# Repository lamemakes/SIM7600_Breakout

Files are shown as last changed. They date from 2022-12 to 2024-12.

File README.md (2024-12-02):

# SIM7600 Breakout Board
*Needs a cooler name, huh?*

## TLDR
This project is a 4 layer PCB built around the SIM7600 to expose all of it's functionality to make it usable/hackable for a wide range of devices, with a form factor that can fit beautifully on a 30 row breadboard.

## Why?
The intent of this was to be able to experiment with 4G/LTE, learn more about how cellular networks function, and to eventually build something that utilizes these networks along with the SIM7600.

## KiCAD
The required symbols/footprints/3D models can be found in the directories: lib_sch/sim7600_breakout.pretty/3dmodels respectively.

## Usage Pre-Requisites
- A fully assembled lamemakes SIM7600 Breakout Board
- Antennas for respective purposes
    - 50Ω passive LTE/4G w/ U.FL connector
    - 50Ω **active/powered** GPS/GNSS w/ U.FL connector)
- An activated Nano SIM card
    - Carrier _shouldn't_ matter, see **IMEI** section
- Device that supports some form of serial communication
    - UART, I2C, and SPI are all supported.
- _(Optional)_ Wired headphones, ideally with about a 35Ω impedence.

## Usage 
The breakout board can be initialized by connecting +3.3v to the +3v3 pin, and ground to the GND pin. Then, turn the module on by pulling the PKEY HIGH.

## Pics

*Schematic*
SIM7600 Breakout Board Schematic

*PCB*
SIM7600 Breakout Board Schematic

## Notes
- **Be a good neighbor on the RF spectrum!** There is certainly a lot of grey area when it comes to legality and LTE/carrier service, so be conscientious - stay within local law. 
- As of writing (12/09/22) this has yet to be constructed. The OSH Park order is out, but the SIM7600G-H is backordered at Digikey along with literally every other SIM7600 model. Hoping for a restock before the new year.
- Contribute! This is my first real RF/4G PCB, so if you see somewhere that could be improved feel free to raise an issue or put up a PR.
- As this is assembled and tinkered with, this README will be immensely updated for better usage instructions.
- It's clear the language barrier is an issue when it comes to the SIM7600 docs, but these resources helped me out a ton:
    - [Xinyuan LilyGO/T](https://github.com/Xinyuan-LilyGO/T-SIM7600X)
    - [CircuitMess Ringo](https://github.com/CircuitMess/CircuitMess-Ringo) <- such a cool project, look to do something very similar moving forward
    - [Waveshare SIM7600 HAT docs](https://www.waveshare.com/wiki/SIM7600E-H_4G_HAT)

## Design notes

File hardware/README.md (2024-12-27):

# SIM7600 Breakout Board Hardware

## BOM

A list of the parts used & where they can be found

| Part No. | Ref Des | Link | Quantity | Notes |
| --- | --- | --- | --- | --- |
| 2137160001 | `J5` | [Digikey](https://www.digikey.com/en/products/detail/molex/2137160001/13662558) | | USB C 2.0 Receptacle |
| SIM7600G R2 | `U3` | [Digikey](https://www.digikey.com/en/products/detail/simcom-wireless-solutions-limited/SIM7600G-R2/15841466) | 1 | SIMCom Wireless LTE Module |
| NAU8810YG | `U4` | [Digikey](https://www.digikey.com/en/products/detail/nuvoton-technology-corporation/NAU8810YG/4271435) | 1 | Audio Codec |
| NVT2008PW,118 | `U1`, `U2` | [Digikey](https://www.digikey.com/en/products/detail/nxp-usa-inc/nvt2008pw-118/2530413) | 2 | Serial Logic Shifter |
| SIM8060-6-0-14-00-A | `J1` | [Digikey](https://www.digikey.com/en/products/detail/gct/sim8060-6-0-14-00-a/9859630) | 1 | Nano SIM Card Holder |
| MMBT3904L RFG | `Q1` | [Digikey](https://www.digikey.com/en/products/detail/taiwan-semiconductor-corporation/mmbt3904l-rfg/7357838) | 1 | NPN BJT for SIM7600 Power Key |
| PESD2V0Y1BSFYL | `D5` | [Digikey](https://www.digikey.com/en/products/detail/nexperia-usa-inc/pesd2v0y1bsfyl/8628181) | 1 | TVS Diode |
| ESD9L5.0ST5G | `D3`, `D4` | [Digikey](https://www.digikey.com/en/products/detail/onsemi/ESD9L5-0ST5G/1693175) | 2 | TVS Diode (USB Data) |
| U.FL-R-SMT-1(01) | `J6`, `J7`, `J8` | [Digikey](https://www.digikey.com/en/products/detail/hirose-electric-co-ltd/U-FL-R-SMT-1-01/3978494) | 3 | Male U.FL 50Ω Receptacle |
| MJ-3502N | `J3` | [Digikey](https://www.digikey.com/en/products/detail/cui-devices/MJ-3502N/281266) | 1 | 3.5mm Headphone Phone Jack |
| AOM-4542P-R | `MK1` | [Digikey](https://www.digikey.com/en/products/detail/pui-audio-inc/AOM-4542P-R/1745490) | 1 | Analog Condenser Microphone |
| C0603C220J5GACTU | `C1`, `C2`, `C3` | [Digikey](https://www.digikey.com/en/products/detail/kemet/C0603C220J5GACTU/411055) | 3 | 22pF caps |
| CL10B104KO8NNNC | `C4`, `C9`, `C10`, `C12` | [Digikey](https://www.digikey.com/en/products/detail/samsung-electro-mechanics/CL10B104KO8NNNC/3886663) | 1 | 0.1uF cap |
| CL10A106MQ8NNNC | `C5` | [Digikey](https://www.digikey.com/en/products/detail/samsung-electro-mechanics/CL10A106MQ8NNNC/3886777) | 1 | 10uF cap |
| CL10A475KP8NNNC | `C6`, `C23`, `C24`, `C25`, `C26` | [Digikey](https://www.digikey.com/en/products/detail/samsung-electro-mechanics/CL10A475KP8NNNC/3886702) | 1 | 4.7uF cap |
| CL10B105KP8NNNC | `C7`, `C8` | [Digikey](https://www.digikey.com/en/products/detail/samsung-electro-mechanics/CL10B105KP8NNNC/3887604) | 1 | 1uF cap |
| CL10C330JB8NNNC | `C27` | [Digikey](https://www.digikey.com/en/products/detail/samsung-electro-mechanics/CL10C330JB8NNNC/3886728) | 1 | 33pF cap |
| GRM188R60J476ME15D  | `C19`, `C22` | [Digikey](https://www.digikey.com/en/products/detail/murata-electronics/GRM188R60J476ME15D/5877410) | 2 | 47uF cap |
| 150120RS75000 | `D1`, `D2` | [Digikey](https://www.digikey.com/en/products/detail/w%C3%BCrth-elektronik/150120RS75000/4489939) | 2 | Red LED |
| M20-9990245 | `J2` | [Digikey](https://www.digikey.com/en/products/detail/harwin-inc/M20-9990245/3728225) | 1 | 1x2 2.54mm male header pins |
| BSCH0010050547NJCP  | `L1` | [Digikey](https://www.digikey.com/en/products/detail/pulse-electronics/BSCH0010050547NJCP/10508660) | 1 | 47nH inductor |
| RC0201JR-0747KL | `R1`, `R2`, `R3`, `R9`, `R10`, `R11`, `R12`, `R13` | [Digikey](https://www.digikey.com/en/products/detail/yageo/RC0201JR-0747KL/1948954) | 8 | 47kΩ resistor |
| RC0201FR-074K7L | `R4`, `R8`, `R19`, `R20`, `R21` | [Digikey](https://www.digikey.com/en/products/detail/yageo/RC0201FR-074K7L/1948894) | 5 | 4k7Ω resistor |
| RC0201JR-075K1L | `R5`, `R24` | [Digikey](https://www.digikey.com/en/products/detail/yageo/RC0201JR-075K1L/5280770) | 1 | 5k1Ω resistor |
| RC0201FR-0722RL | `R6`, `R7` | [Digikey](https://www.digikey.com/en/products/detail/yageo/RC0201FR-0722RL/5280378) | 2 | 22Ω resistor |
| RC0201FR-071K3L | `R14`, `R15` | [Digikey](https://www.digikey.com/en/products/detail/yageo/RC0201FR-071K3L/3202386) | 2 | 1k3Ω resistor |
| RC0201FR-07390RL | `R16`, `R17` | [Digikey](https://www.digikey.com/en/products/detail/yageo/RC0201FR-07390RL/3202404) | 2 | 390Ω resistor |
| RC0201FR-0710RL | `R18` | [Digikey](https://www.digikey.com/en/products/detail/yageo/RC0201FR-0710RL/1948874) | 1 | 10Ω resistor |
| RC0201FR-072K2L | `R22`, `R23` | [Digikey](https://www.digikey.com/en/products/detail/yageo/RC0201FR-072K2L/5280432) | 2 | 2k2Ω resistor |

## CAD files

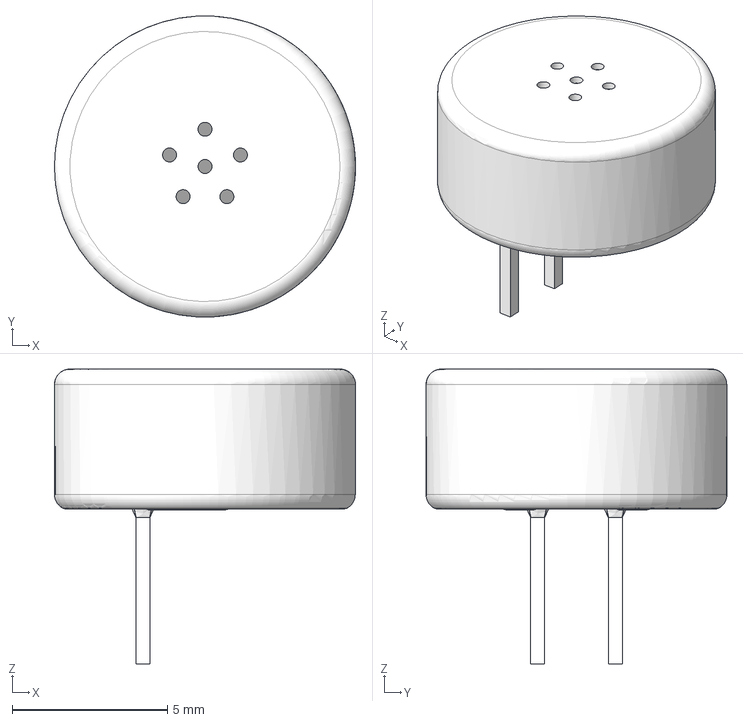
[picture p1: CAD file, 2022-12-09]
hardware/v0.1/3dmodels/AOM-4544P-NF-R.step
9.70 x 9.70 x 9.50 mm

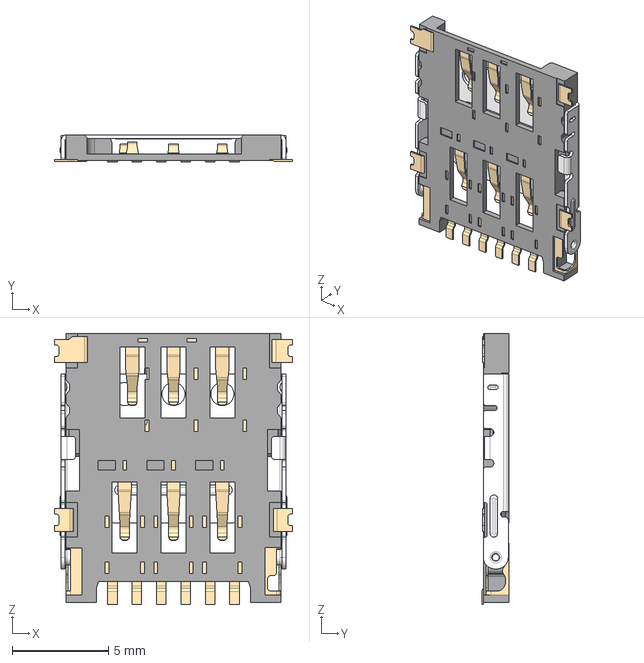
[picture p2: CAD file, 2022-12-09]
hardware/v0.1/3dmodels/SIM8060-6-0-14-00-A.stp
12.4 x 1.43 x 14.1 mm
SIM8060-6-0-14-00-A_PART2
SIM8060-6-0-14-00-A_PART1

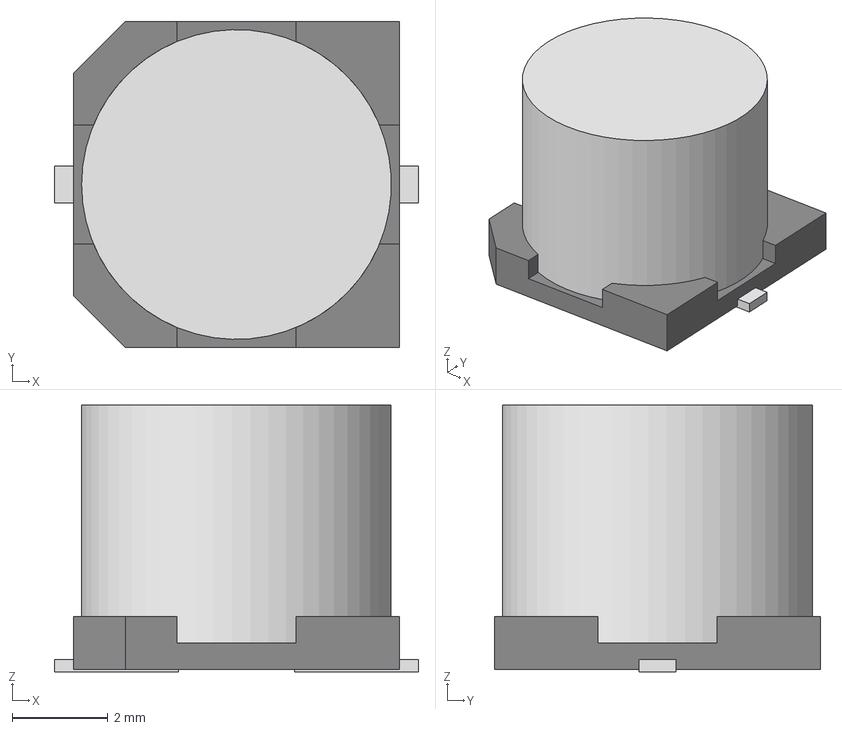
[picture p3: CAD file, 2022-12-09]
hardware/v0.1/3dmodels/CAP_0543009_WRE.step
7.59 x 6.81 x 5.57 mm

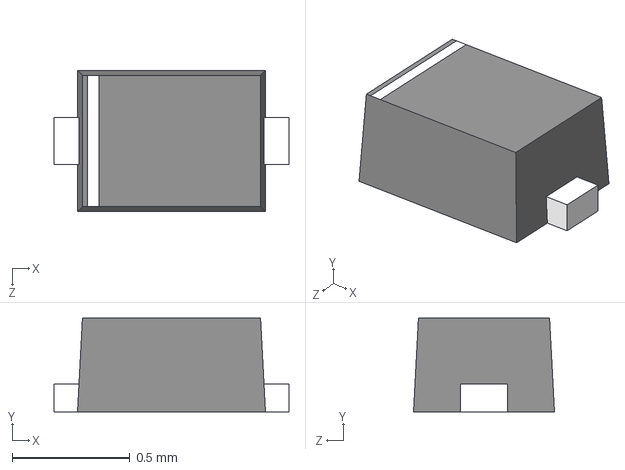
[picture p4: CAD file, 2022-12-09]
hardware/v0.1/3dmodels/ESD9L5.0ST5G.step
1 x 0.4 x 0.6 mm

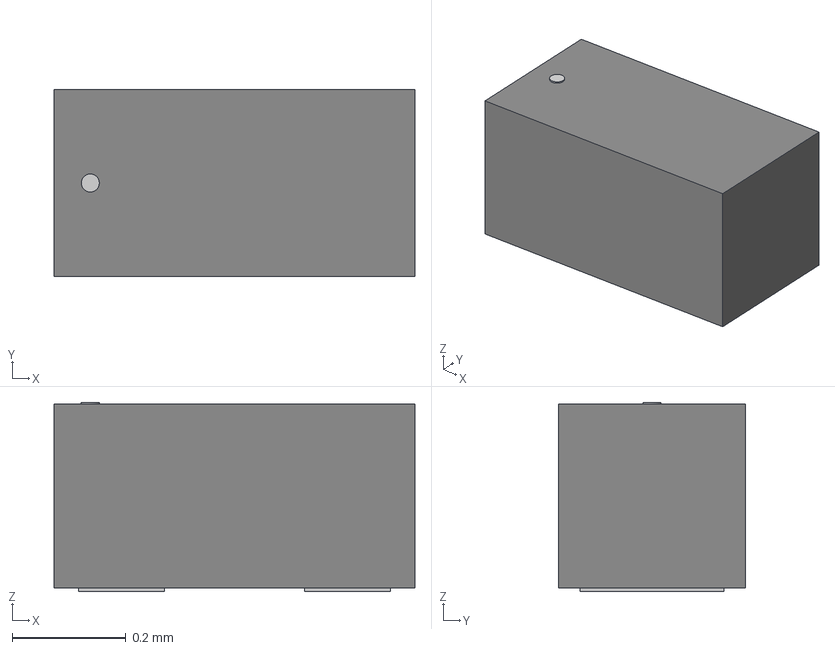
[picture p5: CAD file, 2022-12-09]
hardware/v0.1/3dmodels/CR_Y1BSFYL_NEX.step
0.636 x 0.33 x 0.333 mm

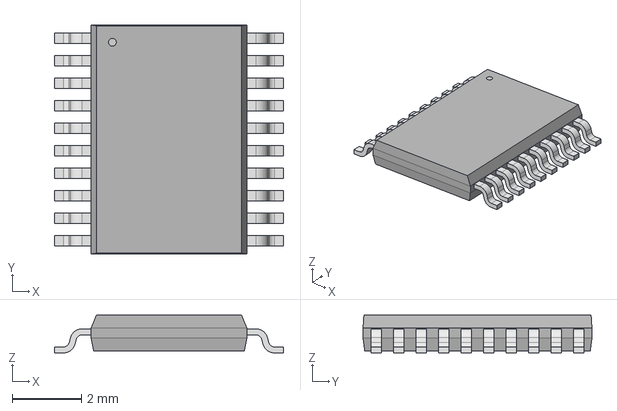
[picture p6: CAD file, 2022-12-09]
hardware/v0.1/3dmodels/TSSOP20_SOT360-1_NXP.step
6.60 x 6.60 x 1.09 mm

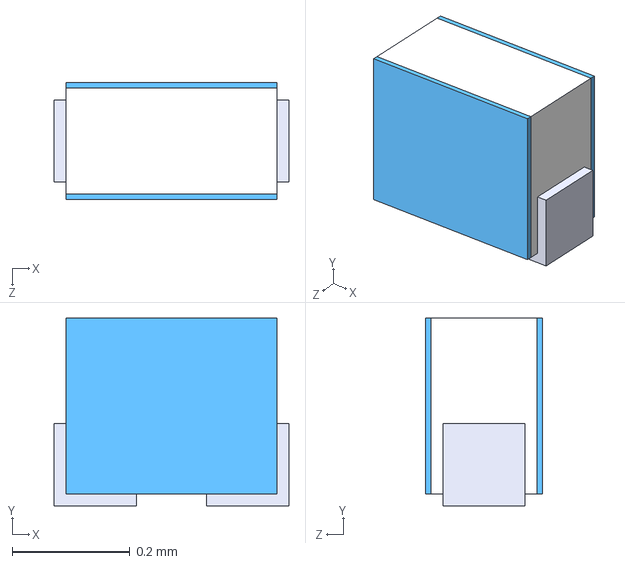
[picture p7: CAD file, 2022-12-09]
hardware/v0.1/3dmodels/LQP02HQ47NH02E.step
0.4 x 0.32 x 0.2 mm

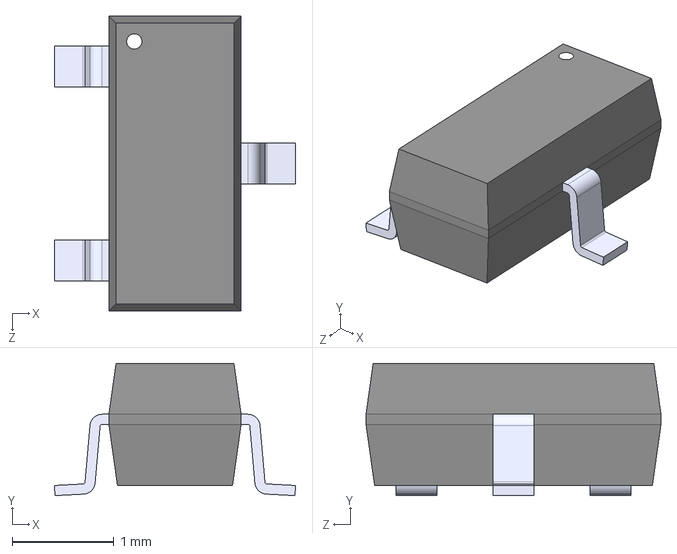
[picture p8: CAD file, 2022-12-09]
hardware/v0.1/3dmodels/MMBT3904L_RFG.step
2.37 x 1.30 x 2.90 mm

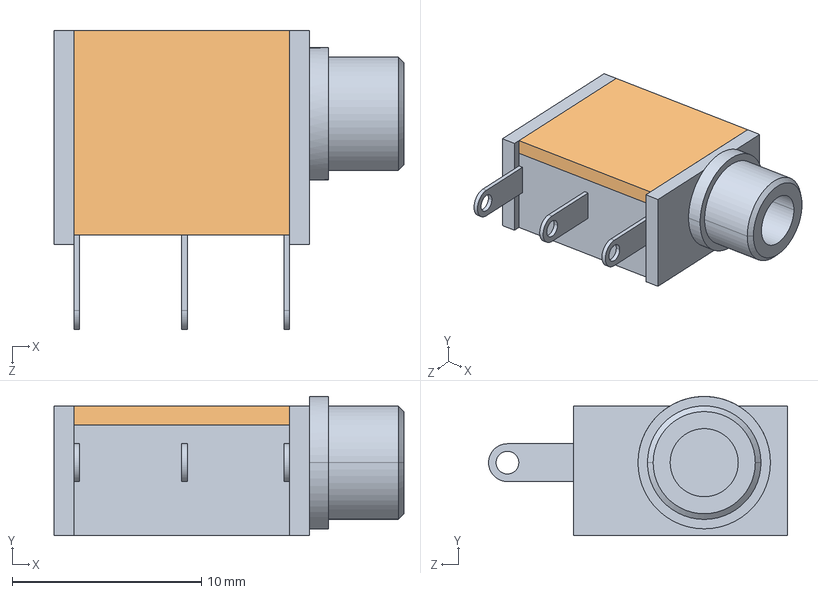
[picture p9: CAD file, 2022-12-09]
hardware/v0.1/3dmodels/CUI_DEVICES_MJ-3502N.step
18.5 x 7.35 x 15.8 mm

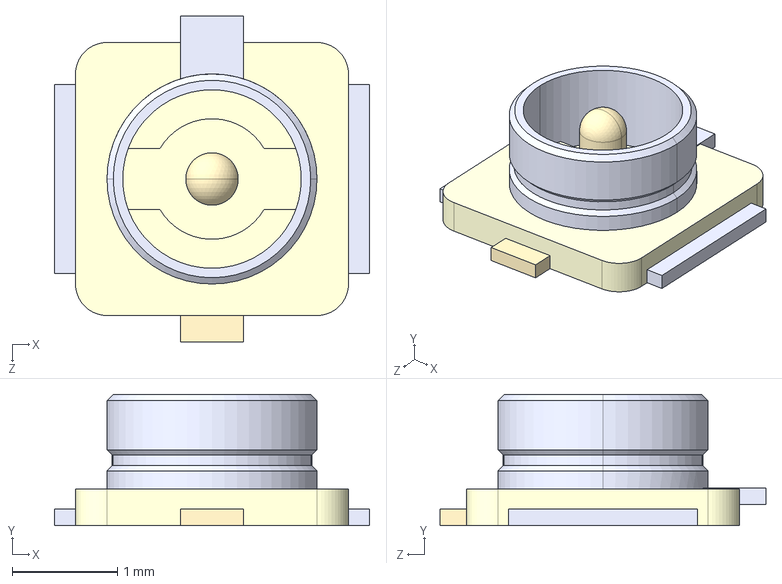
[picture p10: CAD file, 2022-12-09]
hardware/v0.1/3dmodels/U.FL-R-SMT-1_01_.step
3.00 x 1.25 x 3.10 mm

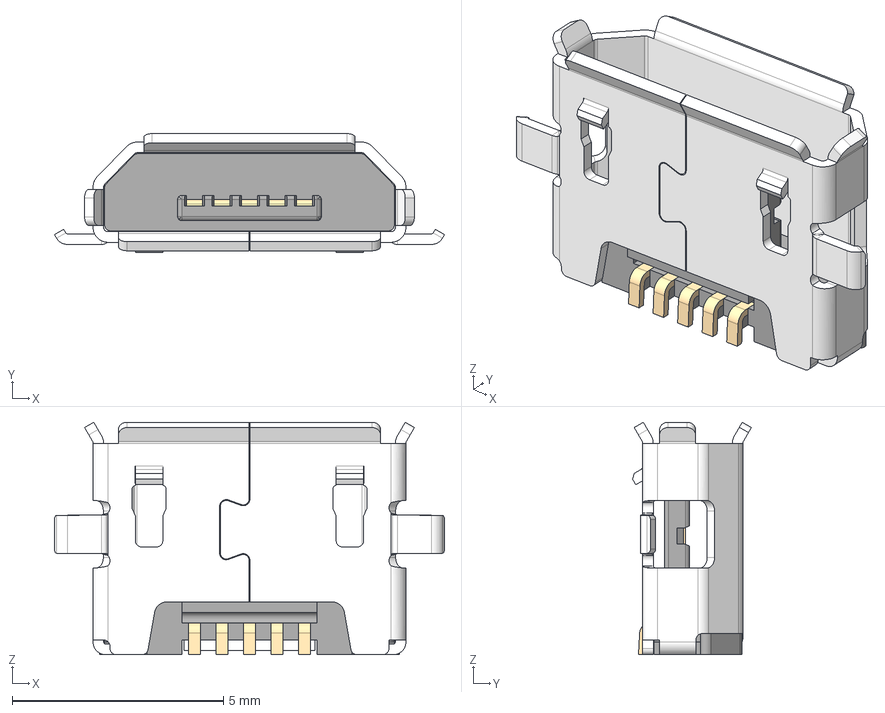
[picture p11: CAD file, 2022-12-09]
hardware/v0.1/3dmodels/usb3100_30_a.stp
9.23 x 2.81 x 5.50 mm
usb3100_30_a_PART7
usb3100_30_a_PART6
usb3100_30_a_PART5
usb3100_30_a_PART4
usb3100_30_a_PART3
usb3100_30_a_PART2
usb3100_30_a_PART1

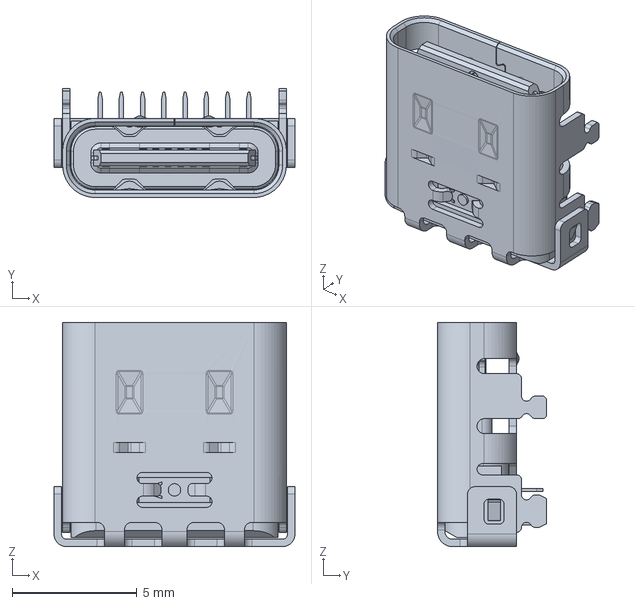
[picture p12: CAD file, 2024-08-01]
hardware/v0.1/3dmodels/2137160001-USB-C.stp
9.64 x 4.36 x 8.97 mm

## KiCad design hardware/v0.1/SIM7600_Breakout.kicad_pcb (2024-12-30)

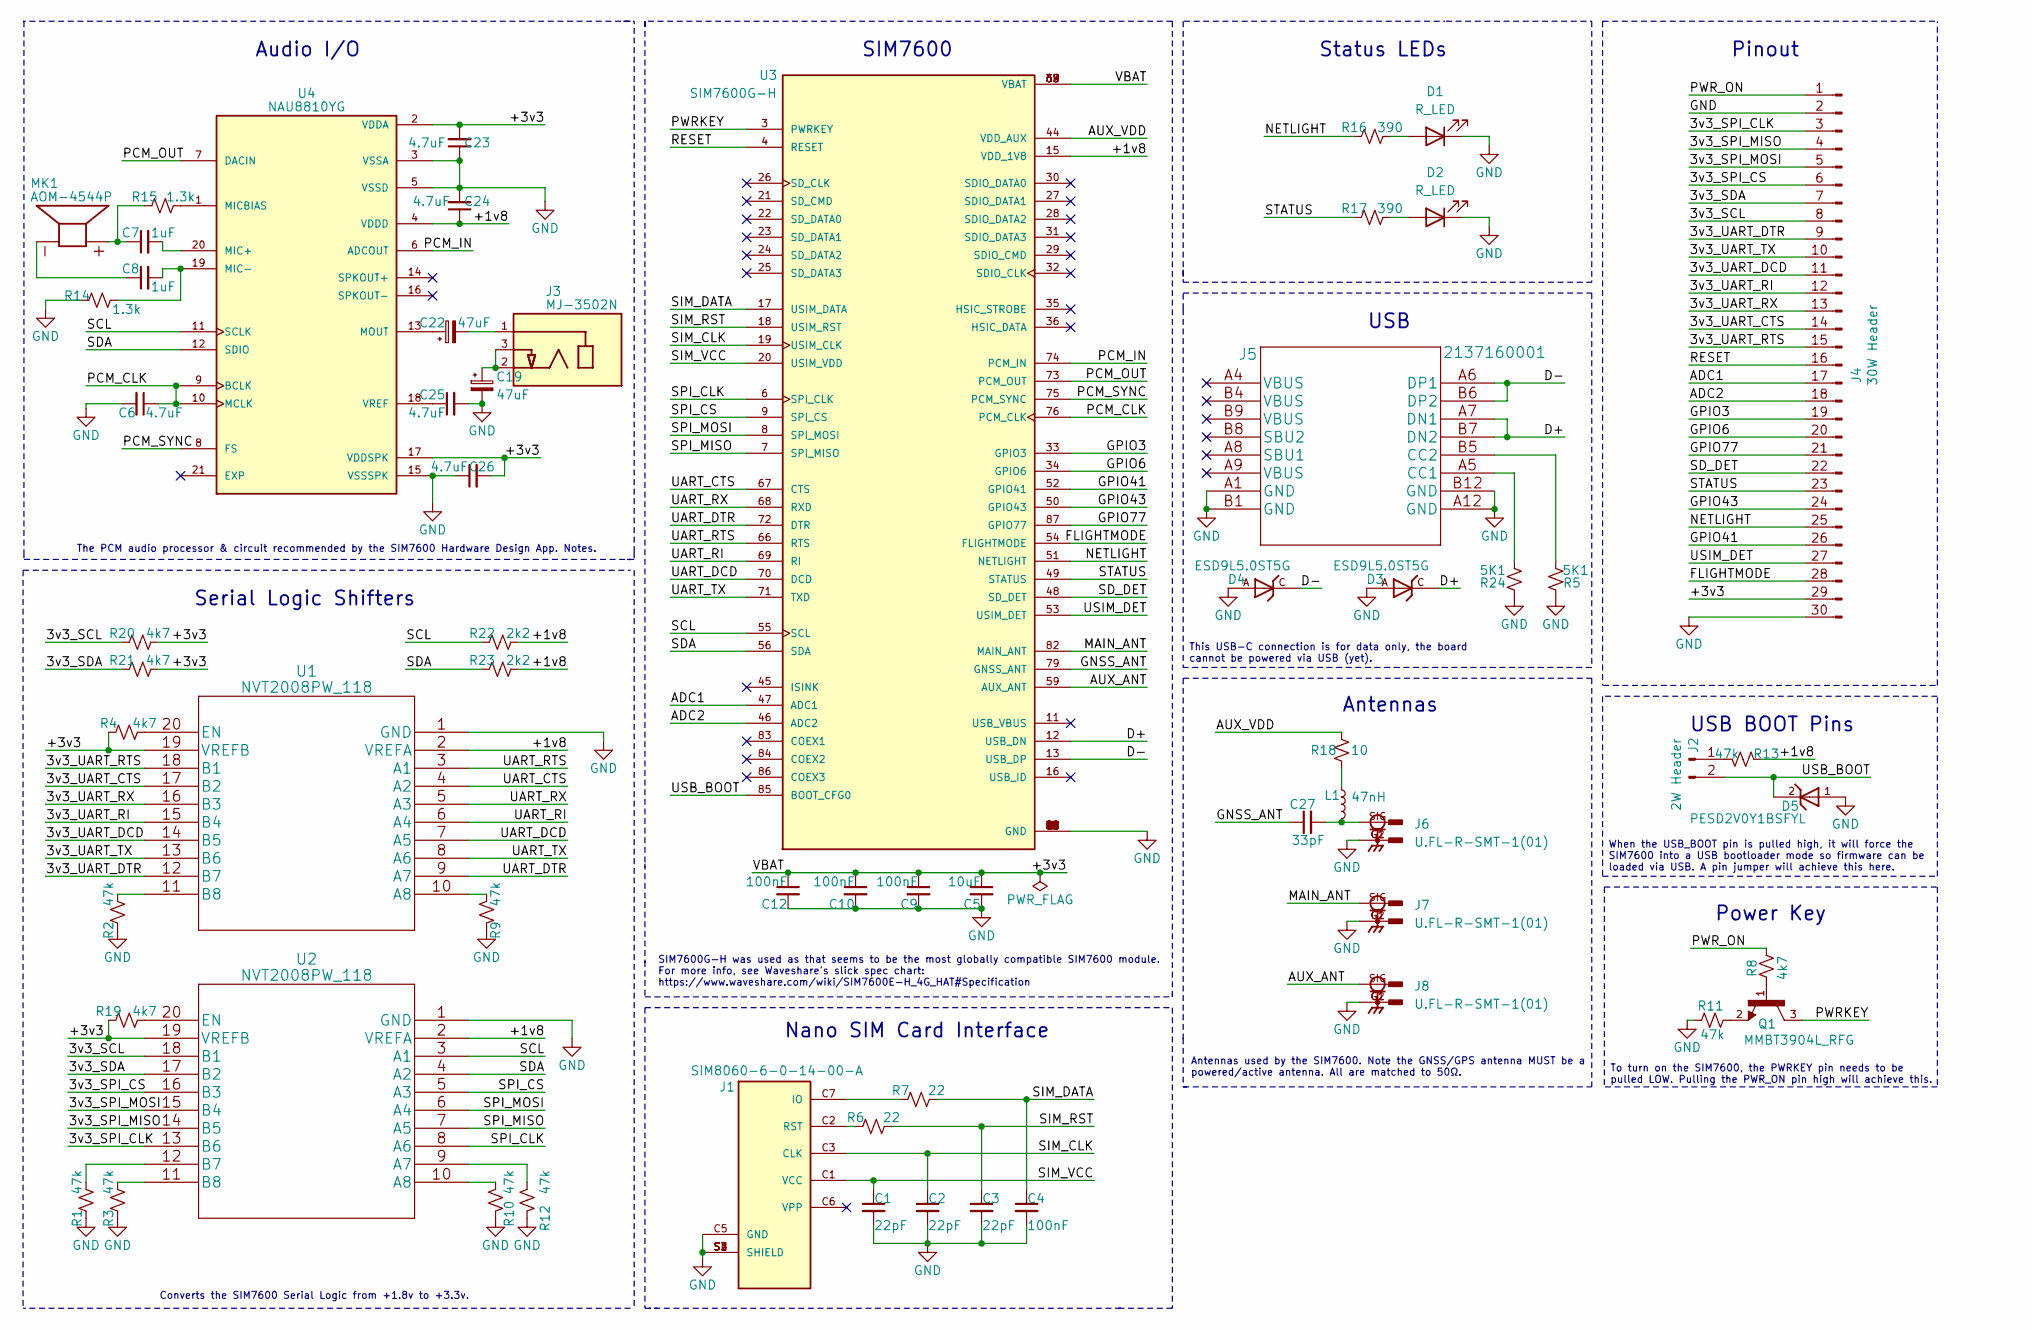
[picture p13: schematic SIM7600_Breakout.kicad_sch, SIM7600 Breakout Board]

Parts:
C1, C2, C3: 22pF; C_0603_1608Metric_Pad1.08x0.95mm_HandSolder
C4, C9, C10, C12: 100nF; C_0603_1608Metric_Pad1.08x0.95mm_HandSolder
C5: 10uF; C_0603_1608Metric_Pad1.08x0.95mm_HandSolder
C6, C23, C24, C25, C26: 4.7uF; C_0603_1608Metric_Pad1.08x0.95mm_HandSolder
C7, C8: 1uF; C_0603_1608Metric_Pad1.08x0.95mm_HandSolder
C19, C22: 47uF; 865080543009
C27: 33pF; C_0603_1608Metric_Pad1.08x0.95mm_HandSolder
D1, D2: R_LED; LED_1206_3216Metric_Pad1.42x1.75mm_HandSolder
D3, D4: ESD9L5.0ST5G; DIOM1006X40N; PARTREV 7
D5: PESD2V0Y1BSFYL; PARTREV 7
J1: SIM8060-6-0-14-00-A; GCT_SIM8060-6-0-14-00-A
J2: 2W Header; PinHeader_1x02_P2.54mm_Vertical
J3: MJ-3502N; CUI_MJ-3502N; PART_REV A
J4: 30W Header; PinHeader_1x30_P2.54mm_Vertical
J5: 2137160001; 2137160001-USB-C
J6, J7, J8: U.FL-R-SMT-1(01); HIROSE_U.FL-R-SMT-1(01); PARTREV Jul.1.2022
L1: 47nH; IND_LQP02HQ47NH02E
MK1: AOM-4544P; MIC_AOM-4544P-NF-R; PARTREV B
Q1: MMBT3904L_RFG; SOT95P237X112-3N; PARTREV I2001
R1, R2, R3, R9, R10, R11, R12, R13: 47k; R_0201_0603Metric_Pad0.64x0.40mm_HandSolder
R4, R8, R19, R20, R21: 4k7; R_0201_0603Metric_Pad0.64x0.40mm_HandSolder
R5, R24: 5K1; R_0201_0603Metric_Pad0.64x0.40mm_HandSolder
R6, R7: 22; R_0201_0603Metric_Pad0.64x0.40mm_HandSolder
R14, R15: 1.3k; R_0201_0603Metric_Pad0.64x0.40mm_HandSolder
R16, R17: 390; R_0201_0603Metric_Pad0.64x0.40mm_HandSolder
R18: 10; R_0201_0603Metric_Pad0.64x0.40mm_HandSolder
R22, R23: 2k2; R_0201_0603Metric_Pad0.64x0.40mm_HandSolder
U1, U2: NVT2008PW_118
U3: SIM7600G-H; IC_SIM7600E-H; PARTREV 1.01
U4: NAU8810YG; QFN50P400X400X80-21N; PARTREV 2.8

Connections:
/3v3_SCL: J4.8, R20.1, U2.18 (B1)
/3v3_SDA: J4.7, R21.1, U2.17 (B2)
/3v3_SPI_CLK: J4.3, U2.13 (B6)
/3v3_SPI_CS: J4.6, U2.16 (B3)
/3v3_SPI_MISO: J4.4, U2.14 (B5)
/3v3_SPI_MOSI: J4.5, U2.15 (B4)
/3v3_UART_CTS: J4.14, U1.17 (B2)
/3v3_UART_DCD: J4.11, U1.14 (B5)
/3v3_UART_DTR: J4.9, U1.12 (B7)
/3v3_UART_RI: J4.12, U1.15 (B4)
/3v3_UART_RTS: J4.15, U1.18 (B1)
/3v3_UART_RX: J4.13, U1.16 (B3)
/3v3_UART_TX: J4.10, U1.13 (B6)
/+1v8: C24.1, R13.1, R22.2, R23.2, U1.2 (VREFA), U2.2 (VREFA), U3.15 (VDD_1V8), U4.4 (VDDD)
/+3v3: C5.1, C9.1, C10.1, C12.1, C23.2, C26.2, J4.29, R4.1, R19.1, R20.2, R21.2, U1.19 (VREFB), U2.19 (VREFB), U3.38 (VBAT), U3.39 (VBAT), U3.62 (VBAT), U3.63 (VBAT), U4.2 (VDDA), U4.17 (VDDSPK)
/ADC1: J4.17, U3.47 (ADC1)
/ADC2: J4.18, U3.46 (ADC2)
/AUX_ANT: J8.SIG, U3.59 (AUX_ANT)
/AUX_VDD: R18.2, U3.44 (VDD_AUX)
/D+: D3.C, J5.A7 (DN1), J5.B7 (DN2), U3.12 (USB_DN)
/D-: D4.C, J5.A6 (DP1), J5.B6 (DP2), U3.13 (USB_DP)
/FLIGHTMODE: J4.28, U3.54 (FLIGHTMODE)
/GNSS_ANT: C27.1, U3.79 (GNSS_ANT)
/GPIO3: J4.19, U3.33 (GPIO3)
/GPIO6: J4.20, U3.34 (GPIO6)
/GPIO41: J4.26, U3.52 (GPIO41)
/GPIO43: J4.24, U3.50 (GPIO43)
/GPIO77: J4.21, U3.87 (GPIO77)
/MAIN_ANT: J7.SIG, U3.82 (MAIN_ANT)
/NETLIGHT: J4.25, R16.1, U3.51 (NETLIGHT)
/PCM_CLK: C6.1, U3.76 (PCM_CLK), U4.9 (BCLK), U4.10 (MCLK)
/PCM_IN: U3.74 (PCM_IN), U4.6 (ADCOUT)
/PCM_OUT: U3.73 (PCM_OUT), U4.7 (DACIN)
/PCM_SYNC: U3.75 (PCM_SYNC), U4.8 (FS)
/PWRKEY: Q1.3, U3.3 (PWRKEY)
/PWR_ON: J4.1, R8.2
/RESET: J4.16, U3.4 (RESET)
/SCL: R22.1, U2.3 (A1), U3.55 (SCL), U4.11 (SCLK)
/SDA: R23.1, U2.4 (A2), U3.56 (SDA), U4.12 (SDIO)
/SD_DET: J4.22, U3.48 (SD_DET)
/SIM_CLK: C2.1, J1.C3 (CLK), U3.19 (USIM_CLK)
/SIM_DATA: C4.1, R7.2, U3.17 (USIM_DATA)
/SIM_RST: C3.1, R6.2, U3.18 (USIM_RST)
/SIM_VCC: C1.1, J1.C1 (VCC), U3.20 (USIM_VDD)
/SPI_CLK: U2.8 (A6), U3.6 (SPI_CLK)
/SPI_CS: U2.5 (A3), U3.9 (SPI_CS)
/SPI_MISO: U2.7 (A5), U3.7 (SPI_MISO)
/SPI_MOSI: U2.6 (A4), U3.8 (SPI_MOSI)
/STATUS: J4.23, R17.1, U3.49 (STATUS)
/UART_CTS: U1.4 (A2), U3.67 (CTS)
/UART_DCD: U1.7 (A5), U3.70 (DCD)
/UART_DTR: U1.9 (A7), U3.72 (DTR)
/UART_RI: U1.6 (A4), U3.69 (RI)
/UART_RTS: U1.3 (A1), U3.66 (RTS)
/UART_RX: U1.5 (A3), U3.68 (RXD)
/UART_TX: U1.8 (A6), U3.71 (TXD)
/USB_BOOT: D5.2, J2.2, U3.85 (BOOT_CFG0)
/USIM_DET: J4.27, U3.53 (USIM_DET)
GND: C1.2, C2.2, C3.2, C4.2, C5.2, C6.2, C9.2, C10.2, C12.2, C19.2, C23.1, C24.2, C25.2, C26.1, D1.1 (K), D2.1 (K), D3.A, D4.A, D5.1, J1.C5 (GND), J1.S1 (SHIELD), J1.S2 (SHIELD), J1.S3 (SHIELD), J1.S4 (SHIELD), J4.2, J4.30, J5.A1 (GND), J5.A12 (GND), J5.B1 (GND), J5.B12 (GND), J6.G1, J6.G2, J7.G1, J7.G2, J8.G1, J8.G2, R1.1, R2.1, R3.1, R5.1, R9.1, R10.1, R11.1, R12.1, R14.1, R24.1, U1.1 (GND), U2.1 (GND), U3.1 (GND), U3.2 (GND), U3.5 (GND), U3.10 (GND), U3.14 (GND), U3.37 (GND), U3.40 (GND), U3.41 (GND), U3.43 (GND), U3.57 (GND), U3.58 (GND), U3.60 (GND), U3.61 (GND), U3.64 (GND), U3.65 (GND), U3.77 (GND), U3.78 (GND), U3.80 (GND), U3.81 (GND), U4.3 (VSSA), U4.5 (VSSD), U4.15 (VSSSPK)
unnamed: C7.1, MK1.P, R15.1
unnamed: C8.1, MK1.N
unnamed: C19.1, J3.2, J3.3
unnamed: C22.2, J3.1
unnamed: C27.2, J6.SIG, L1.2
unnamed: D1.2 (A), R16.2
unnamed: D2.2 (A), R17.2
unnamed: J1.C7 (IO), R7.1
unnamed: J1.C2 (RST), R6.1
unnamed: J2.1, R13.2
unnamed: J5.A5 (CC1), R24.2
unnamed: J5.B5 (CC2), R5.2
unnamed: L1.1, R18.1
unnamed: Q1.1, R8.1
unnamed: Q1.2, R11.2
unnamed: R9.2, U1.10 (A8)
unnamed: R2.2, U1.11 (B8)
unnamed: R4.2, U1.20 (EN)
unnamed: R12.2, U2.9 (A7)
unnamed: R10.2, U2.10 (A8)
unnamed: R1.2, U2.12 (B7)
unnamed: R3.2, U2.11 (B8)
unnamed: R19.2, U2.20 (EN)
unnamed: C7.2, U4.20 (MIC+)
unnamed: C8.2, R14.2, U4.19 (MIC-)
unnamed: R15.2, U4.1 (MICBIAS)
unnamed: C22.1, U4.13 (MOUT)
unnamed: C25.1, U4.18 (VREF)

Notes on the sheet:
USB BOOT Pins
Nano SIM Card Interface
The PCM audio processor & circuit recommended by the SIM7600 Hardware Design App. Notes.
SIM7600G-H was used as that seems to be the most globally compatible SIM7600 module. For more info, see Waveshare's slick spec chart: https://www.waveshare.com/wiki/SIM7600E-H_4G_HAT#Specification
SIM7600
Antennas used by the SIM7600. Note the GNSS/GPS antenna MUST be a powered/active antenna. All are matched to 50Ω.
Power Key
Audio I/O
Converts the SIM7600 Serial Logic from +1.8v to +3.3v.
This USB-C connection is for data only, the board cannot be powered via USB (yet).
To turn on the SIM7600, the PWRKEY pin needs to be pulled LOW. Pulling the PWR_ON pin high will achieve this.
Antennas
Pinout
USB
Serial Logic Shifters
Status LEDs
When the USB_BOOT pin is pulled high, it will force the SIM7600 into a USB bootloader mode so firmware can be loaded via USB. A pin jumper will achieve this here.

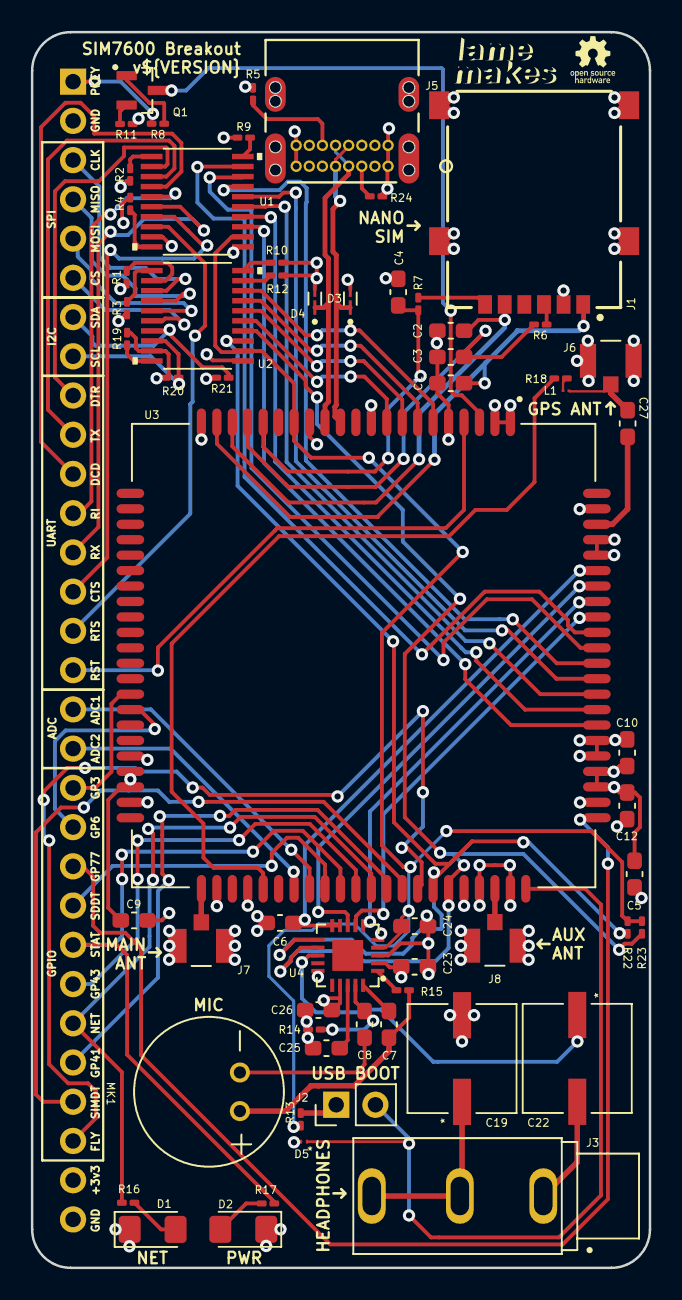
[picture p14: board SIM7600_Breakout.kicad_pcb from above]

Board: 4 copper layers, 40.0 x 80.0 mm, 62 parts (1 on the bottom side), 87 nets.

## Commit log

2022-12-09 Initial board commit
    [AOM-4544P-NF-R.step, CAP_0543009_WRE.step, CR_Y1BSFYL_NEX.step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]
2022-12-09 Documentation updates + pics
    [SIM7600_Breakout.kicad_sch]
2022-12-09 PCB label update
    [SIM7600_Breakout.kicad_pcb]
2022-12-20 Minor fixes
    [SIM7600_Breakout.kicad_pcb, SIM7600_Breakout.kicad_sch]
2024-08-01 Updated models to use USB-C & added a BOM to track parts/links
    [2137160001-USB-C.stp, SIM7600_Breakout.kicad_pcb, SIM7600_Breakout.kicad_sch]
2024-08-03 Added mic to BOM
2024-08-09 Added USB C to schematic & half assed putting it on the PCB
    [SIM7600_Breakout.kicad_pcb, SIM7600_Breakout.kicad_sch]
2024-11-18 Cleaning up USB-C addition
    [SIM7600_Breakout.kicad_pcb]
2024-11-19 "it's USB 2.0 I don't care", logo updates
    [SIM7600_Breakout.kicad_pcb]
2024-12-02 Updated README & added KiCad image generator action
    [2137160001-USB-C.stp, AOM-4544P-NF-R.step, CAP_0543009_WRE.step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]
2024-12-02 Update KiCad Image
2024-12-27 Added BOM and updated gitignore
    [SIM7600_Breakout.kicad_sch]
2024-12-30 Added project wide versioning, cleaned up & added PCB text
    [2137160001-USB-C.stp, AOM-4544P-NF-R.step, CAP_0543009_WRE.step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]

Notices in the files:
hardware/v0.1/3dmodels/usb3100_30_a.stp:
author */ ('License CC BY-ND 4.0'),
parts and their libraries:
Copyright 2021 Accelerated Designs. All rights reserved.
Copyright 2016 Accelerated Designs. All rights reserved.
